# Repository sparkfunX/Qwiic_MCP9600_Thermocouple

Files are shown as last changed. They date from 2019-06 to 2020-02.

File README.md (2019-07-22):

SparkFun MCP9600 Thermocouple Amplifier
========================================

SparkX MCP9600 Thermocouple Amplifier

[*Thermocouple Amplifier (SPX-15508)*](https://www.sparkfun.com/products/15508)

The MCP9600 is an integrated thermocouple amplifier featuring a typical accuracy of ±0.5°C and a maximum accuracy of ±1.5°C, with support for many thermocouple types, conversion modes, and a configurable exponential moving average filter.

Repository Contents
-------------------

* **/Documentation** - Data sheets, additional product information
* **/Hardware** - Eagle design files (.brd, .sch)
* **/Production** - Production panel files (.brd)

Documentation
--------------
* **[SparkFun MCP9600 Arduino Library](https://github.com/sparkfun/SparkFun_MCP9600_Arduino_Library)** - Arduino library for the MCP9600.

License Information
-------------------

This product is _**open source**_! 

Please review the LICENSE.md file for license information. 

If you have any questions or concerns on licensing, please contact technical support on our [SparkFun forums](https://forum.sparkfun.com/viewforum.php?f=152).

Distributed as-is; no warranty is given.

- Your friends at SparkFun.

_<COLLABORATION CREDIT>_

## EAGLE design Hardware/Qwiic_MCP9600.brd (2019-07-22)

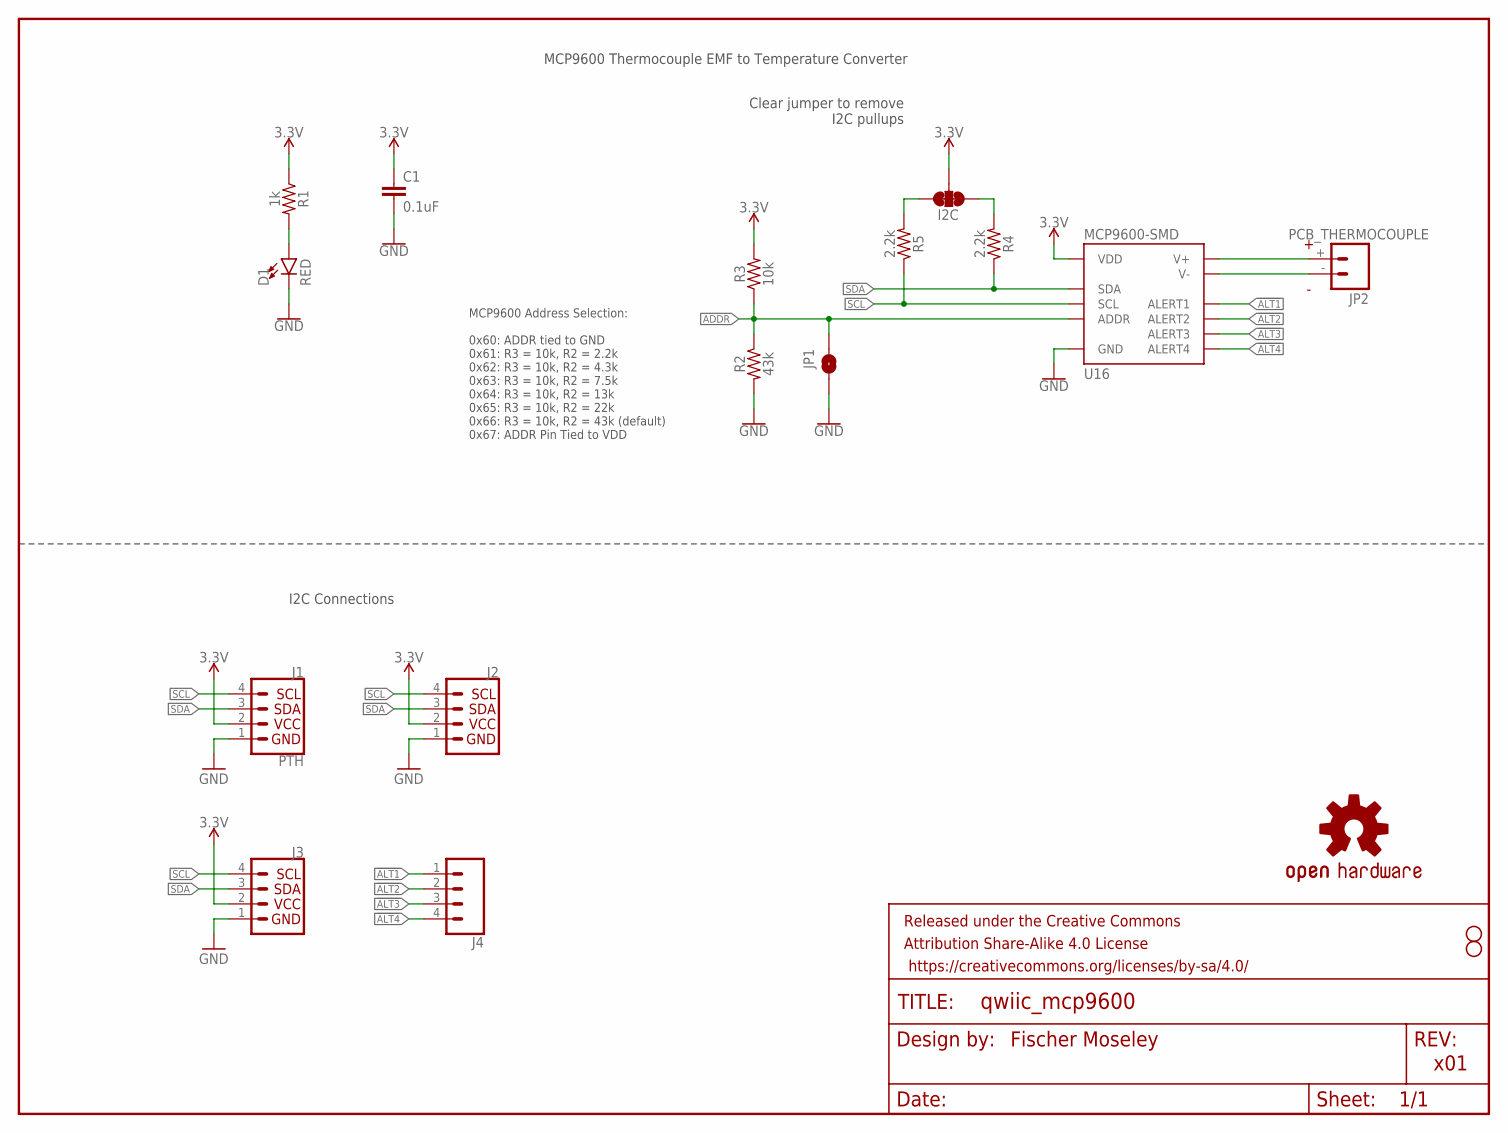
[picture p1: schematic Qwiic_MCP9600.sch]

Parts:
C1: 0.1uF; 0603
D1: RED; LED-0603
FRAME1: FRAME-LETTER; CREATIVE_COMMONS
I2C: JUMPER-SMT_3_2-NC_TRACE_SILK; SMT-JUMPER_3_2-NC_TRACE_SILK
J1: PTH; 1X04_NO_SILK
J2, J3: QWIIC_CONNECTORJS-1MM; JST04_1MM_RA
J4: CONN_041X04_NO_SILK; 1X04_NO_SILK
JP1: JUMPER-SMT_2_NO_SILK; SMT-JUMPER_2_NO_SILK
JP2: PCB_THERMOCOUPLE; PCC-SMP
JP8, JP9: STAND-OFF
LOGO1: OSHW-LOGOMINI; OSHW-LOGO-MINI
R1: 1k; 0603
R2: 43k; 0603
R3: 10k; 0603
R4, R5: 2.2k; 0603
U16: MCP9600-SMD; MQFN-20

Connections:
3.3V: C1.1, I2C.2, J1.2 (VCC), J2.2, J3.2, R1.1, R3.2, U16.8 (VDD)
!ALT1: J4.1, U16.11 (ALERT1)
!ALT2: J4.2, U16.12 (ALERT2)
!ALT3: J4.3, U16.14 (ALERT3)
!ALT4: J4.4, U16.15 (ALERT4)
ADDR: JP1.1, R2.1, R3.1, U16.16 (ADDR)
GND: C1.2, D1.C, J1.1 (GND), J2.1, J3.1, JP1.2, R2.2, U16.1 (GND), U16.3 (GND), U16.5 (GND), U16.6 (GND), U16.7 (GND), U16.9 (GND), U16.10 (GND), U16.13 (GND), U16.17 (GND), U16.18 (GND), U16.21 (GND)
unnamed: D1.A, R1.2
unnamed: I2C.1, R5.2
unnamed: I2C.3, R4.2
unnamed: JP2.+, U16.2 (V+)
unnamed: JP2.-, U16.4 (V-)
SCL: J1.4 (SCL), J2.4, J3.4, R5.1, U16.19 (SCL)
SDA: J1.3 (SDA), J2.3, J3.3, R4.1, U16.20 (SDA)

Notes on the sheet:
I2C Connections
MCP9600 Thermocouple EMF to Temperature Converter
Fischer Moseley
Clear jumper to remove I2C pullups
MCP9600 Address Selection: 0x60: ADDR tied to GND 0x61: R3 = 10k, R2 = 2.2k 0x62: R3 = 10k, R2 = 4.3k 0x63: R3 = 10k, R2 = 7.5k 0x64: R3 = 10k, R2 = 13k 0x65: R3 = 10k, R2 = 22k 0x66: R3 = 10k, R2 = 43k (default) 0x67: ADDR Pin Tied to VDD
x01

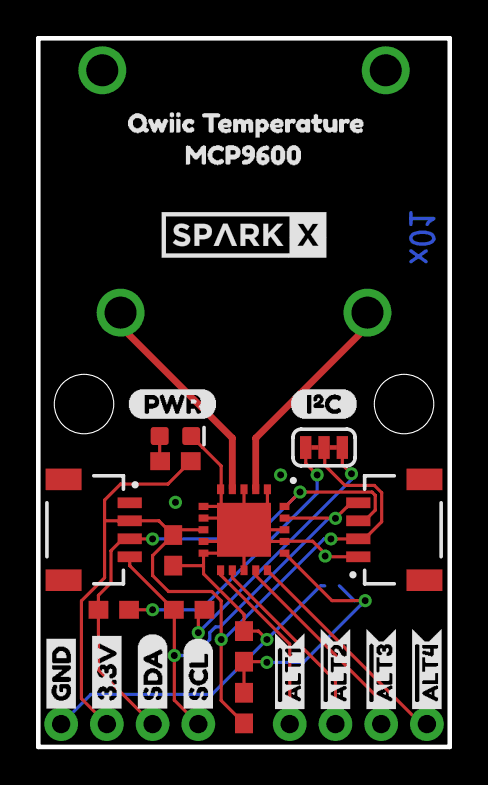
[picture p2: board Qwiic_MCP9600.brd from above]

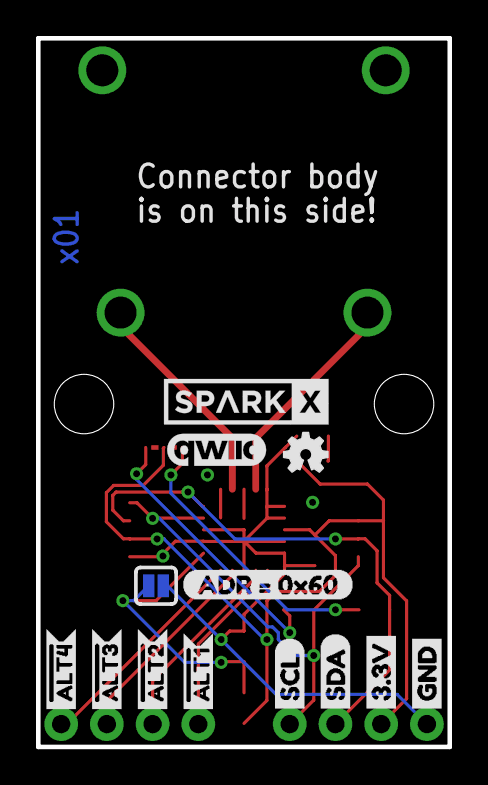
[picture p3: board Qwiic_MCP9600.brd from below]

Board: 2 copper layers, 22.9 x 39.4 mm, 43 parts (14 on the bottom side), 14 nets.

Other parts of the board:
U$1, U$5: #ALT30
U$2, U$17: SPARKX-MEDIUM
U$3, U$8: #ALT10
U$4, U$18: #ALT20
U$6: QWIIC_TEMPERATURE2
U$7, U$11: #ALT40
U$9, U$12: SCL-[)
U$10, U$23: GND-04
U$13, U$14: SDA-[)
U$15: QWIIC_5.5MM
U$19, U$22: 3.3V
U$20: PWR-()-04
U$21: I_SUPER2_C-()-04
U$25: MCP96000
U$27: ADR_#_0X600

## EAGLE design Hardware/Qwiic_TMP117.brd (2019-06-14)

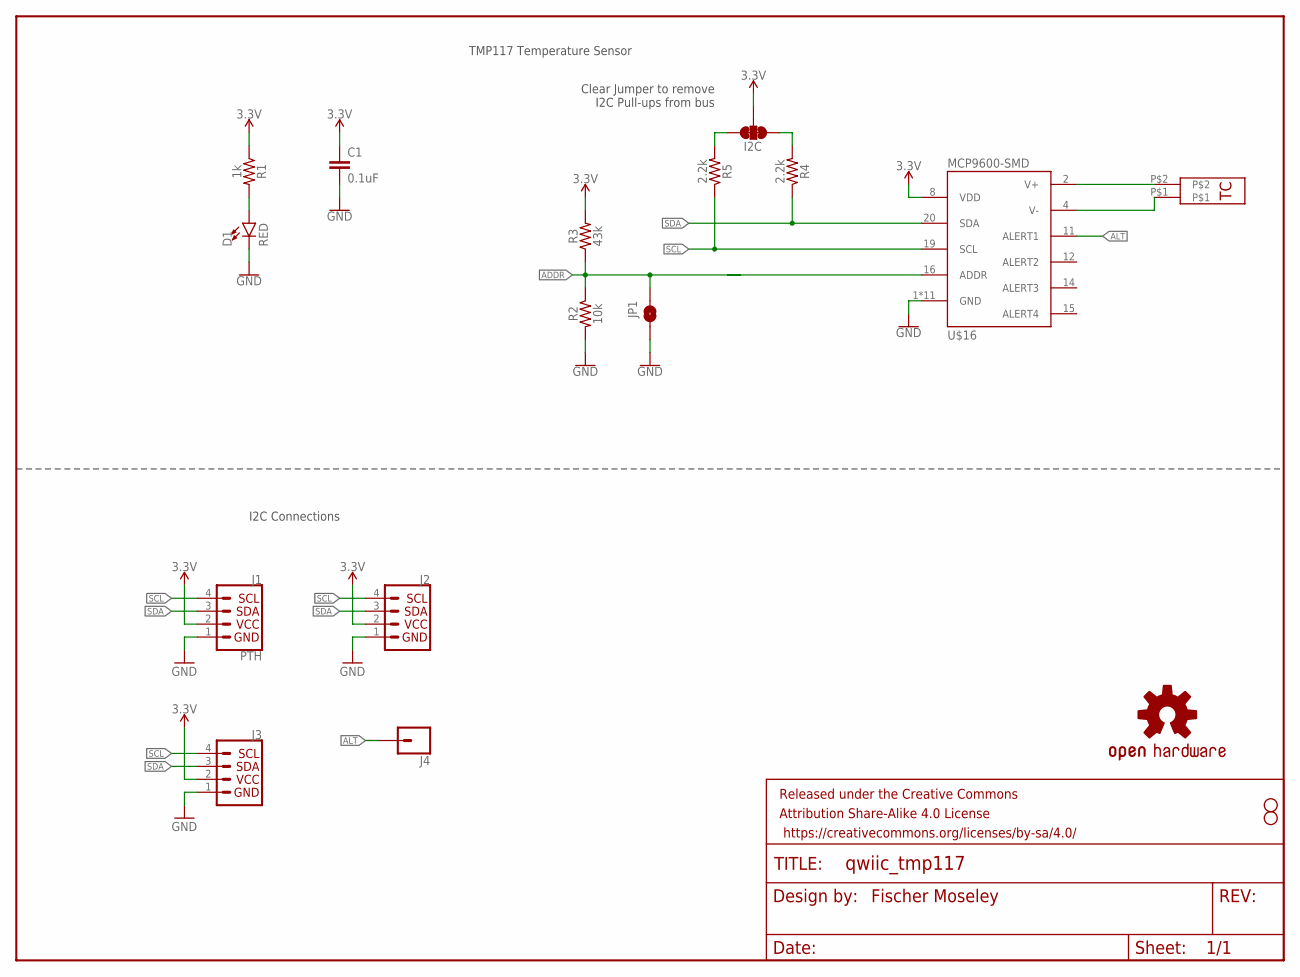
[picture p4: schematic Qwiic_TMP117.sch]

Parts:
C1: 0.1uF; 0603
D1: RED; LED-0603
FRAME1: FRAME-LETTER; CREATIVE_COMMONS
I2C: JUMPER-SMT_3_2-NC_TRACE_SILK; SMT-JUMPER_3_2-NC_TRACE_SILK
J1: PTH; 1X04_NO_SILK
J2, J3: QWIIC_CONNECTORJS-1MM; JST04_1MM_RA
J4: CONN_01PTH_NO_SILK_YES_STOP; 1X01_NO_SILK
JP1: JUMPER-SMT_2_NO_SILK; SMT-JUMPER_2_NO_SILK
JP8, JP9: STAND-OFF
LOGO1: OSHW-LOGOMINI; OSHW-LOGO-MINI
R1: 1k; 0603
R2: 10k; 0603
R3: 43k; 0603
R4, R5: 2.2k; 0603
U$16: MCP9600-SMD; MQFN-20
U$24: CHARLESPAX_TC-MINI-CONNECTOR

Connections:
3.3V: C1.1, I2C.2, J1.2 (VCC), J2.2, J3.2, R1.1, R3.2, U$16.8 (VDD)
ADDR: JP1.1, R2.1, R3.1, U$16.16 (ADDR)
ALT: J4.1, U$16.11 (ALERT1)
GND: C1.2, D1.C, J1.1 (GND), J2.1, J3.1, JP1.2, R2.2, U$16.1 (GND), U$16.3 (GND), U$16.5 (GND), U$16.6 (GND), U$16.7 (GND), U$16.9 (GND), U$16.10 (GND), U$16.13 (GND), U$16.17 (GND), U$16.18 (GND), U$16.21 (GND)
unnamed: D1.A, R1.2
unnamed: I2C.1, R5.2
unnamed: I2C.3, R4.2
unnamed: U$16.2 (V+), U$24.P$2
unnamed: U$16.4 (V-), U$24.P$1
SCL: J1.4 (SCL), J2.4, J3.4, R5.1, U$16.19 (SCL)
SDA: J1.3 (SDA), J2.3, J3.3, R4.1, U$16.20 (SDA)

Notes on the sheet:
I2C Connections
TMP117 Temperature Sensor
Fischer Moseley
Clear Jumper to remove I2C Pull-ups from bus

Board: 2 copper layers, 41 parts (14 on the bottom side), 11 nets, no tracks yet.

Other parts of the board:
U$1: 0X4B1
U$2, U$17: SPARKX-MEDIUM
U$3, U$11: INT#-[<-04
U$4: TMP1171
U$5: 0X4A0
U$6: QWIIC_TEMPERATURE2
U$7: INT-()-04
U$8: 0X493
U$9, U$12: SCL-[)
U$10, U$23: GND-04
U$13, U$14: SDA-[)
U$15: QWIIC_5.5MM
U$18: ADR_#_0X484
U$19, U$22: 3.3V
U$20: PWR-()-04
U$21: I_SUPER2_C-()-04

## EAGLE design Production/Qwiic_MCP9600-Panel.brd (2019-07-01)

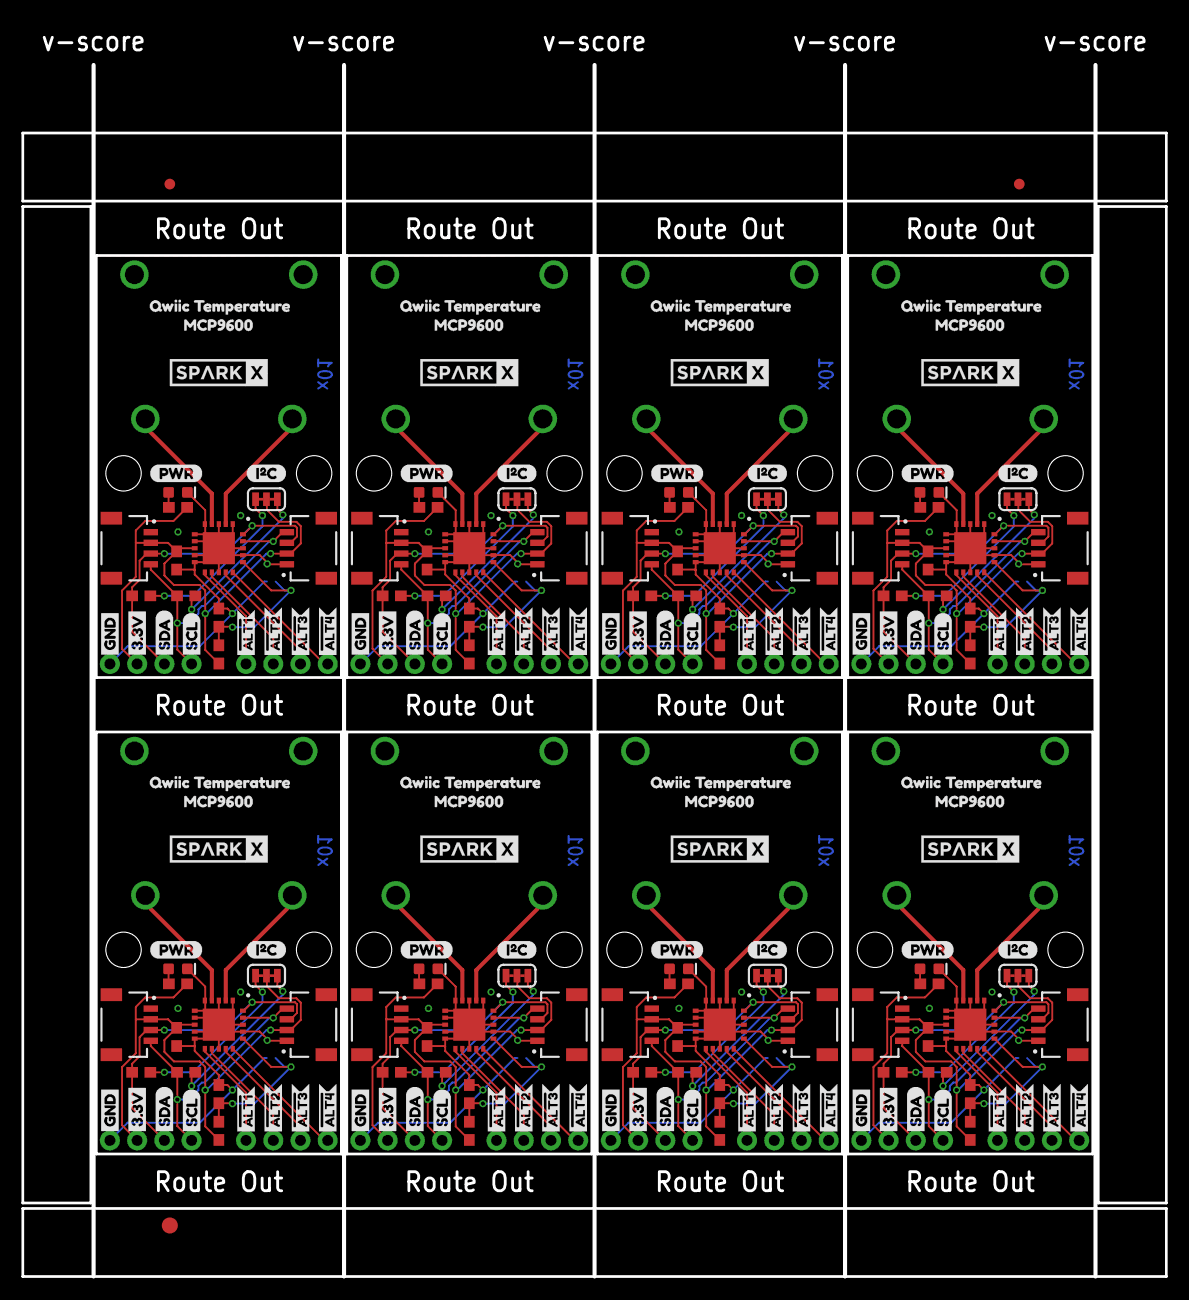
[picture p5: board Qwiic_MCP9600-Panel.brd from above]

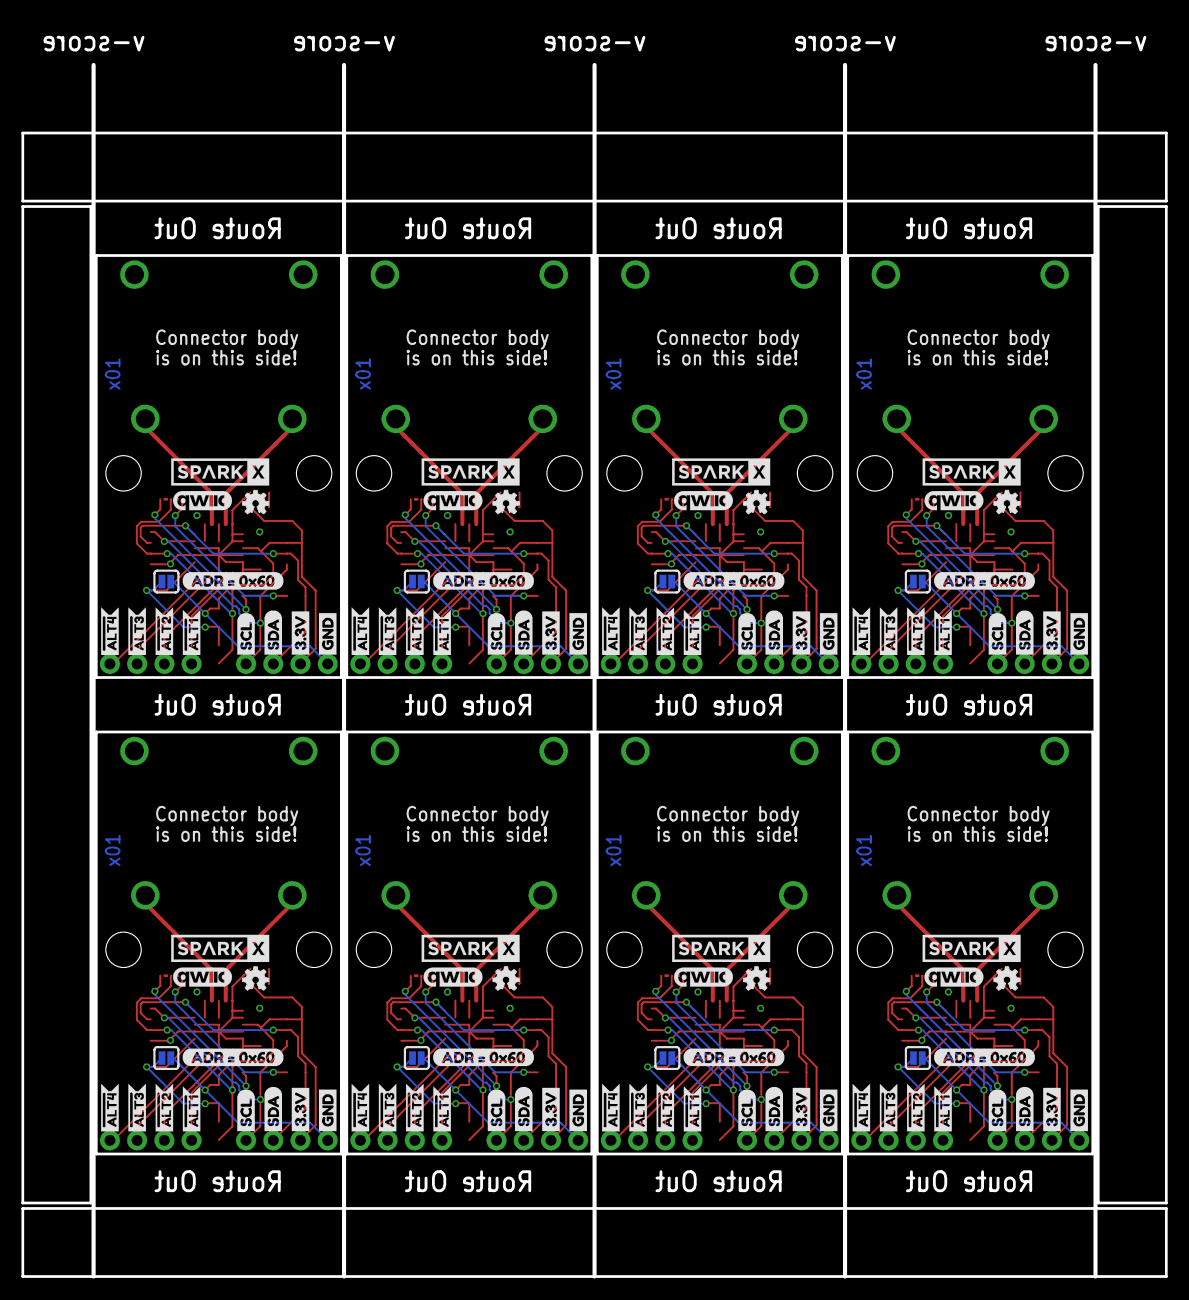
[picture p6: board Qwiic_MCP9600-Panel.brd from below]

Board: 2 copper layers, 106.7 x 113.0 mm, 339 parts (112 on the bottom side), 112 nets.

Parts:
C1, C2, C3, C4, C5, C6, C7, C8: 0.1uF; 0603
D1, D2, D3, D4, D5, D6, D7, D8: RED; LED-0603
E$1, E$2: FIDUCIAL-1X2
E$3: FIDUCIAL-1.5X3
I2C, I2C1, I2C2, I2C3, I2C4, I2C5, I2C6, I2C7: SMT-JUMPER_3_2-NC_TRACE_SILK
J1, J5, J9, J13, J17, J21, J25, J29: PTH; 1X04_NO_SILK
J2, J3, J6, J7, J10, J11, J14, J15, J18, J19, J22, J23, J26, J27, J30, J31: JST04_1MM_RA
J4, J8, J12, J16, J20, J24, J28, J32: 1X04_NO_SILK
JP1, JP3, JP7, JP13, JP17, JP21, JP25, JP29: SMT-JUMPER_2_NO_SILK
JP2, JP6, JP12, JP16, JP20, JP24, JP28, JP32: PCB_THERMOCOUPLE; PCC-SMP
JP4, JP5, JP8, JP9, JP10, JP11, JP14, JP15, JP18, JP19, JP22, JP23, JP26, JP27, JP30, JP31: STAND-OFF
LOGO1, LOGO2, LOGO3, LOGO4, LOGO5, LOGO6, LOGO7, LOGO8: OSHW-LOGOMINI; OSHW-LOGO-MINI
R1, R6, R11, R16, R21, R26, R31, R36: 1k; 0603
R2, R7, R12, R17, R22, R27, R32, R37: 43k; 0603
R3, R10, R15, R20, R25, R30, R35, R40: 10k; 0603
R4, R5, R8, R9, R13, R14, R18, R19, R23, R24, R28, R29, R33, R34, R38, R39: 2.2k; 0603
U1, U2, U3, U4, U5, U6, U7, U16: MCP9600-SMD; MQFN-20
U$1, U$5, U$43, U$47, U$67, U$71, U$91, U$95, U$115, U$119, U$139, U$143, U$163, U$167, U$187, U$191: #ALT30
U$2, U$17, U$24, U$26, U$50, U$51, U$74, U$75, U$98, U$99, U$122, U$123, U$146, U$147, U$170, U$171: SPARKX-MEDIUM
U$3, U$8, U$41, U$45, U$65, U$69, U$89, U$93, U$113, U$117, U$137, U$141, U$161, U$165, U$185, U$189: #ALT10
U$4, U$18, U$42, U$46, U$66, U$70, U$90, U$94, U$114, U$118, U$138, U$142, U$162, U$166, U$186, U$190: #ALT20
U$6, U$16, U$49, U$73, U$97, U$121, U$145, U$169: QWIIC_TEMPERATURE2
U$7, U$11, U$44, U$48, U$68, U$72, U$92, U$96, U$116, U$120, U$140, U$144, U$164, U$168, U$188, U$192: #ALT40
U$9, U$12, U$28, U$35, U$52, U$59, U$76, U$83, U$100, U$107, U$124, U$131, U$148, U$155, U$172, U$179: SCL-[)
U$10, U$23, U$33, U$34, U$57, U$58, U$81, U$82, U$105, U$106, U$129, U$130, U$153, U$154, U$177, U$178: GND-04
U$13, U$14, U$36, U$37, U$60, U$61, U$84, U$85, U$108, U$109, U$132, U$133, U$156, U$157, U$180, U$181: SDA-[)
U$15, U$38, U$62, U$86, U$110, U$134, U$158, U$182: QWIIC_5.5MM
U$19, U$22, U$31, U$32, U$55, U$56, U$79, U$80, U$103, U$104, U$127, U$128, U$151, U$152, U$175, U$176: 3.3V
U$20, U$29, U$53, U$77, U$101, U$125, U$149, U$173: PWR-()-04
U$21, U$30, U$54, U$78, U$102, U$126, U$150, U$174: I_SUPER2_C-()-04
U$25, U$39, U$63, U$87, U$111, U$135, U$159, U$183: MCP96000
U$27, U$40, U$64, U$88, U$112, U$136, U$160, U$184: ADR_#_0X600

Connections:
3.3V: C1.1, I2C.2, J1.2, J2.2, J3.2, R1.1, R3.2, U16.8
3.3V1: C2.1, I2C1.2, J5.2, J6.2, J7.2, R6.1, R10.2, U1.8
3.3V2: C3.1, I2C2.2, J9.2, J10.2, J11.2, R11.1, R15.2, U2.8
3.3V3: C4.1, I2C3.2, J13.2, J14.2, J15.2, R16.1, R20.2, U3.8
3.3V4: C5.1, I2C4.2, J17.2, J18.2, J19.2, R21.1, R25.2, U4.8
3.3V5: C6.1, I2C5.2, J21.2, J22.2, J23.2, R26.1, R30.2, U5.8
3.3V6: C7.1, I2C6.2, J25.2, J26.2, J27.2, R31.1, R35.2, U6.8
3.3V7: C8.1, I2C7.2, J29.2, J30.2, J31.2, R36.1, R40.2, U7.8
!ALT1: J4.1, U16.11
!ALT2: J4.2, U16.12
!ALT3: J4.3, U16.14
!ALT4: J4.4, U16.15
!ALT5: J8.1, U1.11
!ALT6: J8.3, U1.14
!ALT7: J8.4, U1.15
!ALT8: J8.2, U1.12
!ALT9: J12.1, U2.11
!ALT10: J12.3, U2.14
!ALT11: J12.4, U2.15
!ALT12: J12.2, U2.12
!ALT13: J16.1, U3.11
!ALT14: J16.3, U3.14
!ALT15: J16.4, U3.15
!ALT16: J16.2, U3.12
!ALT17: J20.1, U4.11
!ALT18: J20.3, U4.14
!ALT19: J20.4, U4.15
!ALT20: J20.2, U4.12
!ALT21: J24.1, U5.11
!ALT22: J24.3, U5.14
!ALT23: J24.4, U5.15
!ALT24: J24.2, U5.12
!ALT25: J28.1, U6.11
!ALT26: J28.3, U6.14
!ALT27: J28.4, U6.15
!ALT28: J28.2, U6.12
!ALT29: J32.1, U7.11
!ALT30: J32.3, U7.14
!ALT31: J32.4, U7.15
!ALT32: J32.2, U7.12
ADDR: JP1.1, R2.1, R3.1, U16.16
ADDR1: JP3.1, R7.1, R10.1, U1.16
ADDR2: JP7.1, R12.1, R15.1, U2.16
ADDR3: JP13.1, R17.1, R20.1, U3.16
ADDR4: JP17.1, R22.1, R25.1, U4.16
ADDR5: JP21.1, R27.1, R30.1, U5.16
ADDR6: JP25.1, R32.1, R35.1, U6.16
ADDR7: JP29.1, R37.1, R40.1, U7.16
GND: C1.2, D1.C, J1.1, J2.1, J3.1, JP1.2, R2.2, U16.1, U16.3, U16.5, U16.6, U16.7, U16.9, U16.10, U16.13, U16.17, U16.18, U16.21
GND1: C2.2, D2.C, J5.1, J6.1, J7.1, JP3.2, R7.2, U1.1, U1.3, U1.5, U1.6, U1.7, U1.9, U1.10, U1.13, U1.17, U1.18, U1.21
GND2: C3.2, D3.C, J9.1, J10.1, J11.1, JP7.2, R12.2, U2.1, U2.3, U2.5, U2.6, U2.7, U2.9, U2.10, U2.13, U2.17, U2.18, U2.21
GND3: C4.2, D4.C, J13.1, J14.1, J15.1, JP13.2, R17.2, U3.1, U3.3, U3.5, U3.6, U3.7, U3.9, U3.10, U3.13, U3.17, U3.18, U3.21
GND4: C5.2, D5.C, J17.1, J18.1, J19.1, JP17.2, R22.2, U4.1, U4.3, U4.5, U4.6, U4.7, U4.9, U4.10, U4.13, U4.17, U4.18, U4.21
GND5: C6.2, D6.C, J21.1, J22.1, J23.1, JP21.2, R27.2, U5.1, U5.3, U5.5, U5.6, U5.7, U5.9, U5.10, U5.13, U5.17, U5.18, U5.21
GND6: C7.2, D7.C, J25.1, J26.1, J27.1, JP25.2, R32.2, U6.1, U6.3, U6.5, U6.6, U6.7, U6.9, U6.10, U6.13, U6.17, U6.18, U6.21
GND7: C8.2, D8.C, J29.1, J30.1, J31.1, JP29.2, R37.2, U7.1, U7.3, U7.5, U7.6, U7.7, U7.9, U7.10, U7.13, U7.17, U7.18, U7.21
unnamed: D1.A, R1.2
unnamed: I2C.1, R5.2
unnamed: I2C.3, R4.2
unnamed: JP2.+, U16.2
unnamed: JP2.-, U16.4
unnamed: D2.A, R6.2
unnamed: I2C1.1, R9.2
unnamed: I2C1.3, R8.2
unnamed: JP6.+, U1.2
unnamed: JP6.-, U1.4
unnamed: D3.A, R11.2
unnamed: I2C2.1, R14.2
unnamed: I2C2.3, R13.2
unnamed: JP12.+, U2.2
unnamed: JP12.-, U2.4
unnamed: D4.A, R16.2
unnamed: I2C3.1, R19.2
unnamed: I2C3.3, R18.2
unnamed: JP16.+, U3.2
unnamed: JP16.-, U3.4
unnamed: D5.A, R21.2
unnamed: I2C4.1, R24.2
unnamed: I2C4.3, R23.2
unnamed: JP20.+, U4.2
unnamed: JP20.-, U4.4
unnamed: D6.A, R26.2
unnamed: I2C5.1, R29.2
unnamed: I2C5.3, R28.2
unnamed: JP24.+, U5.2
unnamed: JP24.-, U5.4
unnamed: D7.A, R31.2
unnamed: I2C6.1, R34.2
unnamed: I2C6.3, R33.2
unnamed: JP28.+, U6.2
unnamed: JP28.-, U6.4
unnamed: D8.A, R36.2
unnamed: I2C7.1, R39.2
unnamed: I2C7.3, R38.2
unnamed: JP32.+, U7.2
unnamed: JP32.-, U7.4
SCL: J1.4, J2.4, J3.4, R5.1, U16.19
SCL1: J5.4, J6.4, J7.4, R9.1, U1.19
SCL2: J9.4, J10.4, J11.4, R14.1, U2.19
SCL3: J13.4, J14.4, J15.4, R19.1, U3.19
SCL4: J17.4, J18.4, J19.4, R24.1, U4.19
SCL5: J21.4, J22.4, J23.4, R29.1, U5.19
SCL6: J25.4, J26.4, J27.4, R34.1, U6.19
SCL7: J29.4, J30.4, J31.4, R39.1, U7.19
SDA: J1.3, J2.3, J3.3, R4.1, U16.20
SDA1: J5.3, J6.3, J7.3, R8.1, U1.20
SDA2: J9.3, J10.3, J11.3, R13.1, U2.20
SDA3: J13.3, J14.3, J15.3, R18.1, U3.20
SDA4: J17.3, J18.3, J19.3, R23.1, U4.20
SDA5: J21.3, J22.3, J23.3, R28.1, U5.20
SDA6: J25.3, J26.3, J27.3, R33.1, U6.20
SDA7: J29.3, J30.3, J31.3, R38.1, U7.20

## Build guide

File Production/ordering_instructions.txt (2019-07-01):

panel size, 107x107mm
PCB thickness, 1.6mm
number of layers, 2
soldermask color, Black
silkscreen color, White
oz copper, 1oz
finish, HASL lead free
stencils, top
pcs per panel, 8
min trace width, 0.177800mm / 0.007000in
min drill size, 0.381000mm / 0.015000in

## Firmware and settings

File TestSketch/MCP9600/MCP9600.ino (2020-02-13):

/*
  Simple, quick test sketch
*/

#define statLED 5

#include <SparkFun_MCP9600.h>
MCP9600 tempSensor;

void setup() {
  Serial.begin(115200);

  pinMode(statLED, OUTPUT);
  digitalWrite(statLED, LOW);

  Wire.begin();
}

void loop()
{
  if (tempSensor.begin() == true)
  {
    if (tempSensor.available())
    {
      float temperature = tempSensor.getAmbientTemp();
      float delta = tempSensor.getTempDelta();

      Serial.print("Thermocouple: ");
      Serial.print(tempSensor.getThermocoupleTemp());
      Serial.print(" °C   Ambient: ");
      Serial.print(temperature);
      Serial.print(" °C   Temperature Delta: ");
      Serial.print(delta);
      Serial.print(" °C");
      Serial.println();

    if (temperature < 28.0 && temperature > 22.0 && delta < 3.0)
      digitalWrite(statLED, HIGH);
    }
  }
  else
  {
    Serial.println("Nothing detected");
    digitalWrite(statLED, LOW);
  }

  delay(100);
}

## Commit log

2019-06-14 Added datasheet, removed extraneous README's
    [Qwiic_TMP117.brd, Qwiic_TMP117.sch]
2019-06-14 Library created, schematic ready for review, began layout
    [Qwiic_TMP117.brd, Qwiic_TMP117.sch]
2019-06-17 Push before initial layout review
    [Qwiic_MCP9600.brd, Qwiic_MCP9600.sch]
2019-06-18 Push changes made after first layout review
    [Qwiic_MCP9600.brd, Qwiic_MCP9600.sch]
2019-06-18 Changed MCP9600 designator
    U$16 -> U16
    [Qwiic_MCP9600.brd, Qwiic_MCP9600.sch]
2019-06-18 Added addressing information to schematic
    [Qwiic_MCP9600.brd, Qwiic_MCP9600.sch]
2019-07-01 Added production files
    [Qwiic_MCP9600-Panel.GBL, Qwiic_MCP9600-Panel.GBO, Qwiic_MCP9600-Panel.GBS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]
2019-07-22 Updated readme, fixed directory structure
    [Qwiic_MCP9600-Panel.GBL, Qwiic_MCP9600-Panel.GBO, Qwiic_MCP9600-Panel.GBS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]

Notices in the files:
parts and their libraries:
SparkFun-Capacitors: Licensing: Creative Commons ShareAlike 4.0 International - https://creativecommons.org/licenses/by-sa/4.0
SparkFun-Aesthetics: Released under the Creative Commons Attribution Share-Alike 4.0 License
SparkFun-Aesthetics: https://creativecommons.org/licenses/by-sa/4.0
